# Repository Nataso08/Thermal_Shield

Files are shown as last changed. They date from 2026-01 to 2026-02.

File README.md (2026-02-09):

# 💻 Thermal_Shield 🌡️

Un progetto Arduino per il controllo della temperatura tramite una scheda termica e una ventola. 
<br>

## 🧾 Materiali necessari:
- Arduino UNO
- Scheda termica
- Ventola 12 V
- Ponte H

## 🌡️ Scheda termica:
La scheda termica utilizzata nel nostro sistema è stata realizzata dalla nostra scuola, [Istituto Max Planck (Villorba, TV)](https://maxplanck.edu.it).

### 📐 Struttura:
La scheda termica è strutturata su un PCB e si presenta come riportato nelle seguenti immagini.
<br>

<div style="display:flex; gap:10px;">
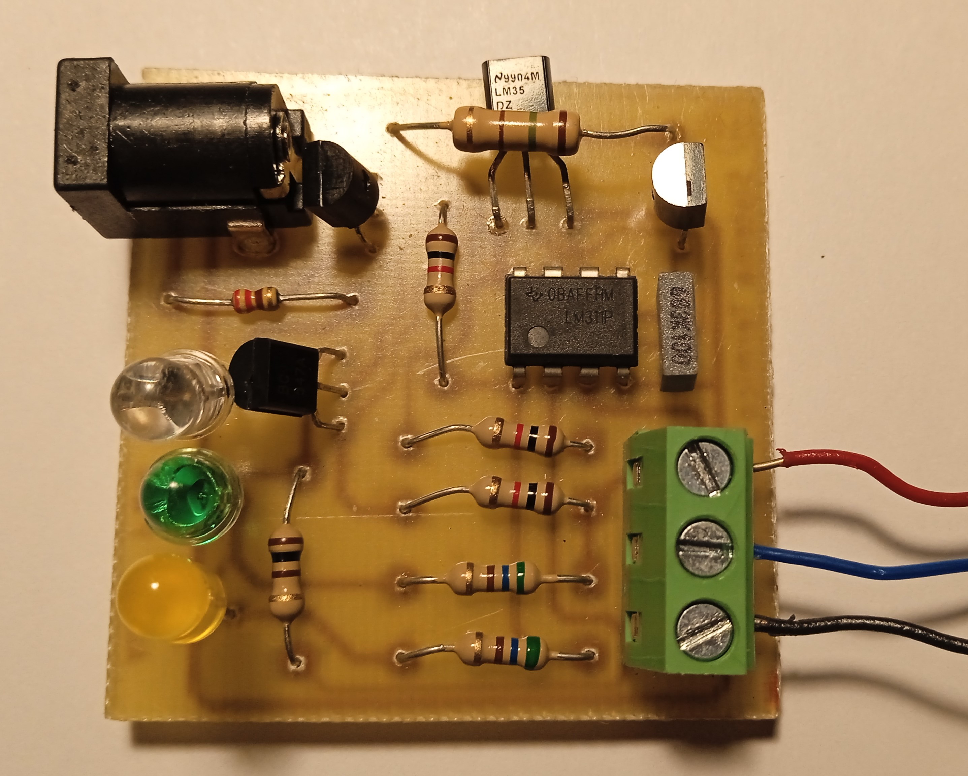
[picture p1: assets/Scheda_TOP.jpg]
Scheda, sopra
  
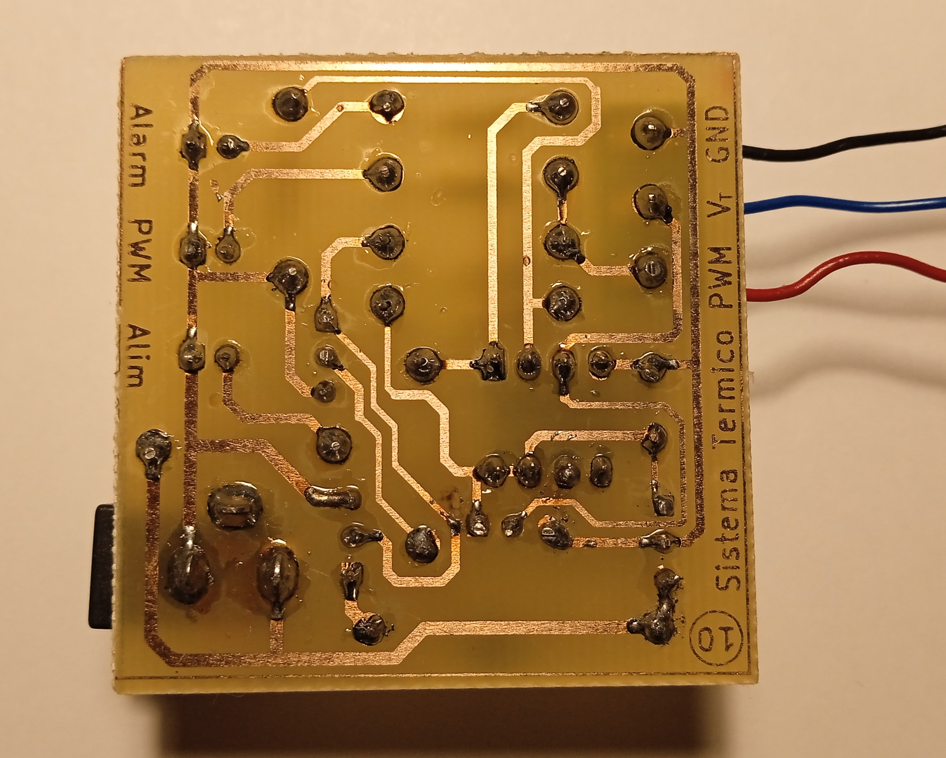
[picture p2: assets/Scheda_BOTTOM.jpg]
Scheda, sotto
  
</div>

### 🖇️ Schema
Di seguito è riportato lo schema elettrico della scheda. <br>
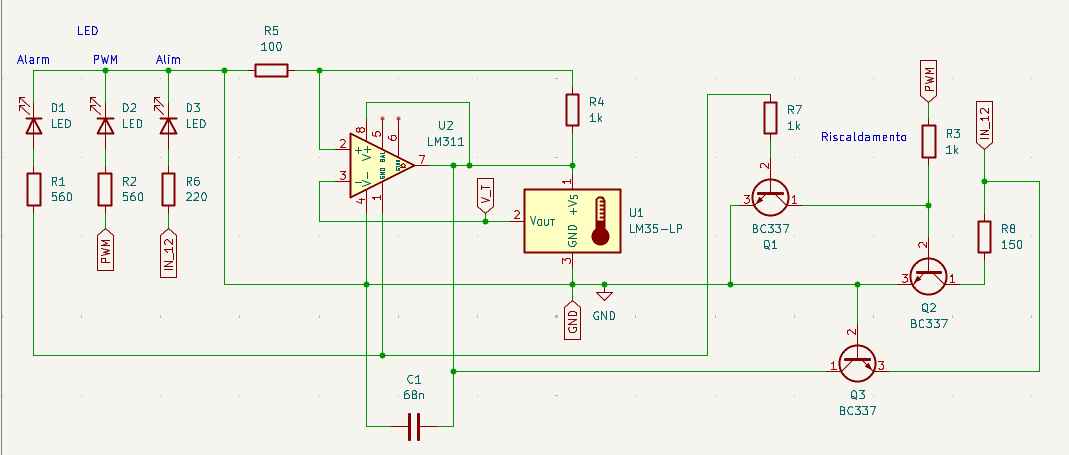
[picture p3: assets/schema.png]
Schema elettrico della scheda


[Progetto Kicad](./Thermal_Shield/Thermal_Shield.kicad_pro)

### 🔌 Collegamenti:

- Alimentare la scheda (jack DC) ad una tensione di 12 V
- Collegare Arduino UNO tramite la morsettiera:
    - GND → GND
    - $V_T$ → Ingresso Analogico di Arduino (A0 - A5)
    - PWM → Uscita PWM di Arduino (pin 3, 5, 6, 9, 10 o 11)

## 💨 Ventola:
Generica ventola 12 V (es. ventola da PC).<br><br>
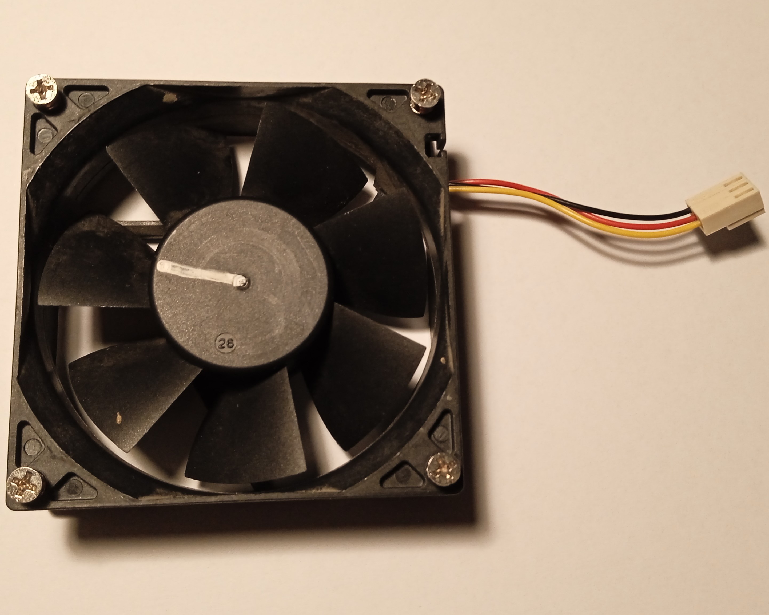
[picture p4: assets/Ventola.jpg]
Ventola 12 V


### 🔌 Collegamenti:
- Power → alimentazione 12 V (tramite [ponte H](#ponte-h))
- GND → GND (comune tra Arduino e alimentazione 12 V)
- RPM → Pin interrupt di Arudino (2, 3)

⚠️ **Non collegare GND all'uscita del ponte H, altrimenti l'encoder non funziona correttamente**. <br>
❗ Nel codice allegato non è presente la misurazione della velocità (RPM) ma è facilmente integrabile.

❗ Collegare 5 V del ponte H a $V_{in}$ di Arduino se si vuole far funzionare il sistema indipendente dall'alimentazione USB. <br>
⚠️ In questo caso, **alimentare il ponte H prima di collegare Arduino con USB** per evitare problemi di alimentazione.
<br><br>

### 🔌 Ponte H:
È possibile usare un qualsiasi ponte H. <br>
Nel mio caso ho utilizzato un L298N, utilizzando esclusivamente il "ramo" B. <br><br>
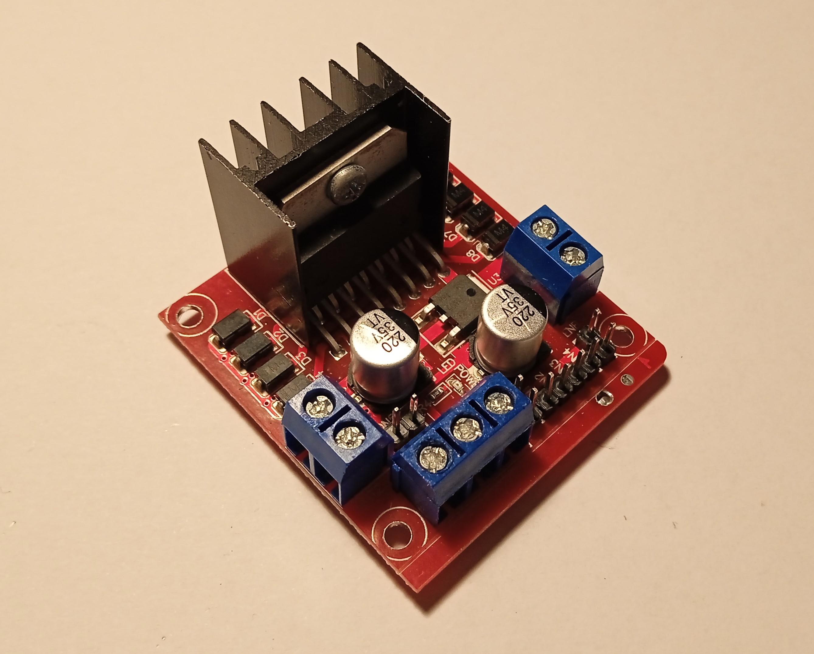
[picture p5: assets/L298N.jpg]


Collegare il pin IN3 (se si utilizza il "ramo" B) ad un'uscita PWM di Arduino (pin 3, 5, 6, 9, 10 o 11). <br>
⚠️ Si può verificare se il l'alimentazione ha polarizzazione corretta cortocircuitando il pin IN3 con i 5 V di Arduino: se la ventola inizia a girare il pin è corretto, altrimenti collegare il pin IN4 (o il complementare della coppia del "ramo" scelto).

#### ❗ Alternative:
Se non si dispone di un ponte H è possibile sostituirlo con un circuito a transistor con dovuto dimensionamento.
<br>

### ⚙️ Filtro segnale PWM:
Poiché il segnale PWM potrebbe non essere propriamente adatto alla tua ventola è consigliabile realizzare un filtro RC come quello di seguito riportato. <br>
...

## 🛠️ Setup:
1) Effettuare i collegamenti sopra descritti
2) Adattare i pin impostati nel [codice allegato](/Thermal_Shield.ino) sulla base delle proprie necessità
3) Impostare i propri valori di T_min e T_max
4) Se necessario, modificare il kp e q (nella funzione FTU) affinché la ventola riesca ad abbassare la temperatura fino a T_min
5) Caricare il [codice allegato](/Thermal_Shield.ino) e aggiornato (vedi punto 2) su Arduino tramite Arduino IDE

## 💻 Utilizzo:

### 🟢 Azionamento:
Si può azionare il sistema tramite:
1) Pressione del pulsante Start
2) Scrittura '1' su Seriale

A seguito di una delle 2 azioni il sistema inizierà il suo ciclo di riscaldamento/raffreddamento.

### 🔴 Spegnimento:
Si può fermare il sistema tramite:
1) Pressione del pulsante Stop
2) Scrittura '0' su Seriale

A seguito di una delle 2 azioni il sistema si fermerà togliendo alimentazione a resistenza riscaldante e ventola (non svolge però la funzione di freno alla ventola, che continuerà a ruotare per inerzia).

### 📊 Misurazione / rappresentazione grafica:
È possibile osservare il variare della temperatura tramite la lettura della comunicazione seriale. In particolare:
- **Monitor Seriale**: Permette una facile lettura dei dati "grezzi" 📄
- **Plotter Seriale**: Permette una facile visualizzazione grafica del variare dei valori 📉

<br>
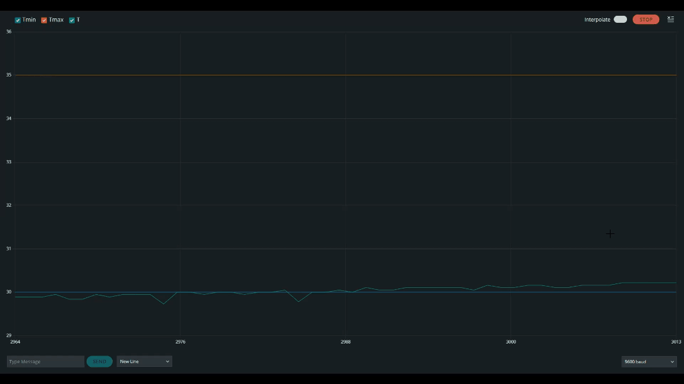
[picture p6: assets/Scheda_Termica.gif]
Grafico Temperatura


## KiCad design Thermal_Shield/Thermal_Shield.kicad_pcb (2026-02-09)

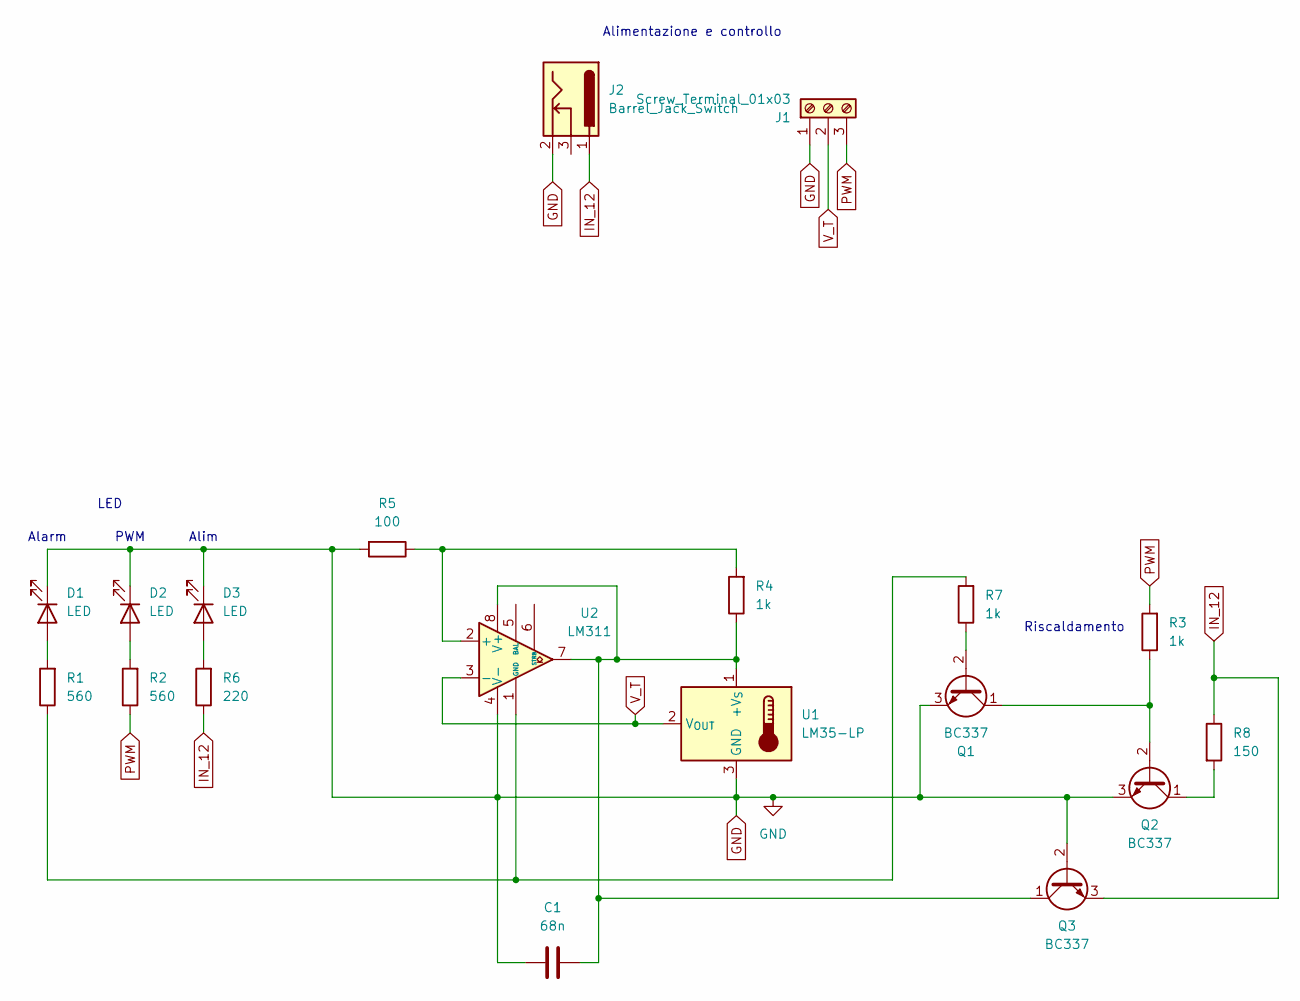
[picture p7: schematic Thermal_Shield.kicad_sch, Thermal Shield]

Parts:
C1: 68n; C_Rect_L7.2mm_W2.5mm_P5.00mm_FKS2_FKP2_MKS2_MKP2
D1, D2, D3: LED; LED_D4.0mm
J1: Screw_Terminal_01x03; TerminalBlock_MaiXu_MX126-5.0-03P_1x03_P5.00mm
J2: Barrel_Jack_Switch; BarrelJack_Horizontal
Q1, Q2, Q3: BC337; TO-92_Inline_Wide
R1, R2: 560; R_Axial_DIN0309_L9.0mm_D3.2mm_P12.70mm_Horizontal
R3, R4, R7: 1k; R_Axial_DIN0309_L9.0mm_D3.2mm_P12.70mm_Horizontal
R5: 100; R_Axial_DIN0309_L9.0mm_D3.2mm_P12.70mm_Horizontal
R6: 220; R_Axial_DIN0309_L9.0mm_D3.2mm_P12.70mm_Horizontal
R8: 150; R_Axial_DIN0309_L9.0mm_D3.2mm_P20.32mm_Horizontal
U1: LM35-LP; TO-92_Inline_Wide
U2: LM311; DIP-8_W7.62mm

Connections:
GND: C1.2, D1.1 (K), D2.1 (K), D3.1 (K), J1.1, J2.2, Q1.3 (E), Q2.3 (E), Q3.2 (B), R5.2, U1.3 (GND), U2.4 (V-)
IN_12: J2.1, Q3.3 (E), R6.1, R8.1
unnamed: D1.2 (A), R1.2
unnamed: D2.2 (A), R2.2
unnamed: D3.2 (A), R6.2
unnamed: Q1.2 (B), R7.1
unnamed: Q1.1 (C), Q2.2 (B), R3.1
unnamed: Q2.1 (C), R8.2
unnamed: C1.1, Q3.1 (C), R4.1, U1.1 (+V_{S}), U2.7, U2.8 (V+)
unnamed: R4.2, R5.1, U2.2 (+)
unnamed: R1.1, R7.2, U2.1 (GND)
PWM: J1.3, R2.1, R3.2
V_T: J1.2, U1.2 (V_{OUT}), U2.3 (-)

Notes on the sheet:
LED
Riscaldamento
PWM
Alim
Alarm
Alimentazione e controllo

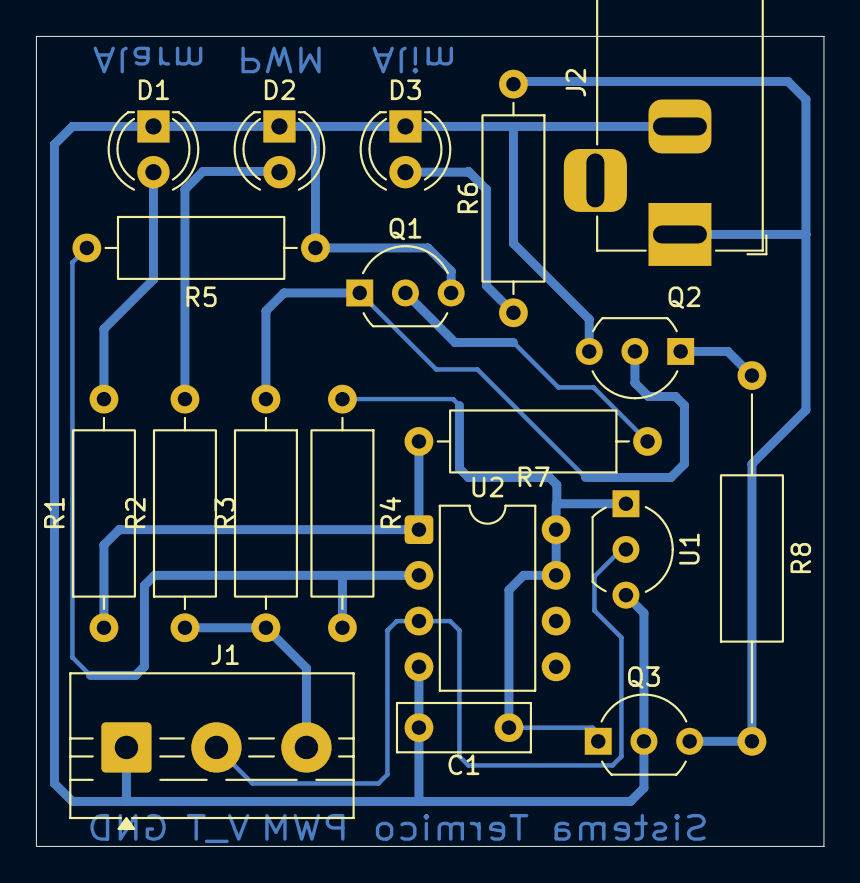
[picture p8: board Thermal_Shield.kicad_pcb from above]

Board: 2 copper layers, 43.8 x 45.0 mm, 19 parts (0 on the bottom side), 13 nets.

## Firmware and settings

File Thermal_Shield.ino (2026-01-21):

#include "mylibrary.h"

/*
PWM Arduino UNO
Pin   | Frequenza   | Timer   | Modalità
3       488 Hz        2         Fast PWM / Phase-correct
5       976 Hz        0         Fast PWM
6       976 Hz        0         Fast PWM
9       488 Hz        1         Fast PWM
10      488 Hz        1         Fast PWM  
11      488 Hz        2         Fast PWM / Phase-correct

Prescaler = 64 per tutti, di default

Definizioni di modalità:
- Fast PWM:
  0 -> TOP (salita) -> 0 (azzero) -> TOP ...
  f_PWM = (16 * 10^6) / (64 * 256) = 976 Hz
- Phase-correct
  0 -> TOP (salita) -> 0 (discesa) -> TOP ...
  f_PWM = (16 * 10^6) / (64 * 2 * 256) = 488 Hz
*/

float T, T_last, T_med, T_max = 35, T_min = 30;      // range di valori nel quale deve essere mantenuta la temperatura

short T_value;      // valore temperatura analogica (0-1023)
short PWM_resistenza, PWM_ventola;    // valore da applicare a pin PWM

// pulsanti START e STOP basati sulla libreria dello scorso anno (debounce e fronti con OOP)
Pulsante Start (4, INPUT_PULLUP, 'n');
Pulsante Stop (5, INPUT_PULLUP, 'n');

#define pinResistenza 10
#define pinVentola 11
#define pinTemp A0

// variabili di stato e definizione stati
char stato, stato_old;
#define ATTESA 0
#define SCALDA 1
#define RAFFREDDA 2

// dichiarazioni funzioni per macchina a stati (Moore)
void FTS ();
void FTU ();
void leggiIngressi ();
void scriviUscite ();

char lettura = '\n';

void setup() {
  // inizializzazione dei pulsanti
  Start.init();
  Stop.init();

  DDRB |= ((1<<PB2) | (1<<PB3));       // setup pin 10 e 11 in OUTPUT tramite registri
  DDRC &= ~(1<<PC0);                   // setup pin A0 in INPUT tramite registri

  // reset variabili di stato
  stato = ATTESA;
  stato_old = 3;

  // analogReference(DEFAULT);           // riferimento default 5 V
  analogReference(INTERNAL);          // riferimento interno 1.1 V
  // analogReference(EXTERNAL);       // riferimento esterno AREF (es. 3.3 V)

  Serial.begin(9600);     // inizializzazione seriale
}

void loop() {
  leggiIngressi ();
  FTS ();
  FTU ();
  scriviUscite ();
}


void FTS () {
  // aggiornamento stato_old
  stato_old = stato;

  // stato = ATTESA se STOP
  if (Stop.f_UP || lettura == '0')
    stato = ATTESA;

  // FTS con controllo temperature (mantenimento tra T_min e T_max)
  switch (stato) {
    case SCALDA:
      if (T_med >= T_max) 
        stato = RAFFREDDA;
      break;
    case RAFFREDDA:
      if (T_med <= T_min) 
        stato = SCALDA;
      break;
    case ATTESA:
    default:
      if (Start.f_UP || lettura == '1')
        stato = SCALDA;
      break;
  }
}

void FTU () {
  // assegnazione valori PWM in base a stato attuale
  switch (stato) {
    case SCALDA:
      PWM_resistenza = 200;
      PWM_ventola = 0;
      break;
    case RAFFREDDA:
      PWM_resistenza = 0;
      // PWM_ventola proporzionale alla differenza di temperatura (più veloce se errore grande)
      double kp = 230, q = 10;
      PWM_ventola = (byte) kp /(T_max - T_min) *(T_med - T_min) + q;
      break;
    case ATTESA:
    default:
      PWM_resistenza = 0;
      PWM_ventola = 0;
      break;
  }
}

void leggiDigital () {
  // lettura pin digitali (START e STOP)
  Start.fronte();
  Stop.fronte();
}
void leggiAnalog () {
  // lettura pin analogici (A0 -> temperatura) ogni 100 ms
  static unsigned long analogTime = 0;    // variabile statica (solo nella funzione, ma mantiene valore)

  if (millis() - analogTime >= 50) {
    analogTime = millis();                

    T_last = T;

    T_value = analogRead (pinTemp);            // lettura analogica di A0
    // calcolo Temperatura con proporzione  
    // lettura : 1023 = T : T_max

    // T = (float) T_value * 500.0 / 1023.0;     // proporzione con REF = 5 V (DEFAULT)
    T = (float) T_value * 110.0 / 1023.0;     // proporzione con REF = 1.1 V (INTERNAL)
    // T = (float) T_value * 330.0 / 1023.0;     // proporzione con es. REF = 3.3 V (EXTERNAL)

    T_med = (T + T_last) /2.0;                // temperatura media ultimi 2 valori -> aiuta a filtraggio software
  } 
}
void leggiSerial () {
  // lettura seriale (char) -> solo "fronte" (se c'è qualcosa salvo quel valore, altrimenti '\n')
  if (Serial.available()) {
    lettura = Serial.read();
  } else lettura = '\n';
}
void leggiIngressi() {
  leggiDigital ();
  leggiAnalog ();
  leggiSerial ();
}


void scriviDigital () {
  // assegnazione valori pin digitali
}
void scriviAnalog () {
  // assegnazione valori pin analogici
  analogWrite(pinResistenza, PWM_resistenza);   // scrittura analogica PWM su pin 10 (resistenza)
  analogWrite(pinVentola, PWM_ventola);
}
void scriviSerial () {
  // scrittura seriale ogni 100 ms (in formato Serial Plotter)
  static unsigned long serialTime = 0;

  if (millis() - serialTime >= 100) {
    serialTime = millis();

    Serial.print ("Tmin:");
    Serial.print (T_min);

    Serial.print (" Tmax:");
    Serial.print (T_max);

    Serial.print (" T:");
    Serial.print (T_med);

    Serial.print ('\n');
  }
}
void scriviUscite () {
  scriviDigital ();
  scriviAnalog ();
  scriviSerial ();
}

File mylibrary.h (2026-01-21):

#ifndef myLibrary
#define myLibrary .h

// dichiaro le costanti del codice (wait di default)
#define DT_WAIT_DEBOUNCE 20
#define DT_M 10000
#define DT_LUCE 1000

// dichiaro classe madre (idealmente astratta, quindi utilizzabile solo da altre classi come stampo; nella pratica accessibile anche dall'esterno (solo public))
class Pin {
  protected: // accessibili solo da sottoclassi
    char set_up;
    unsigned short pin;

    Pin(unsigned short pin, char set_up) : pin(pin), set_up(set_up) {}  // metodo costruttore

  public:
    bool s;

    void init () {
      pinMode (pin, set_up);
    }
};

// dichiaro classe Pulsante come sottoclasse di Pin (assume come propri tutti i parametri e metodi di Pin)
class Pulsante : public Pin {
  private:    // variabili private della classe Pulsante (definizioni + variabili delle funzioni + costanti)
    #define ATTESA 0
    #define CONTROLLO 1
    #define PREMUTO 2
    
    bool lettura;
    char stato_digitalRead_debounced = ATTESA;

    bool letturaFronte;
    bool letturaFronte_old;

    bool POff;
    bool POn;

    int dt_wait_debounce;

    char logic;

    unsigned long tempo;

  public:
    bool f_UP, f_DOWN;

    Pulsante (unsigned short pin, char set_up, char logic = 'p', int dt_wait_debounce = DT_WAIT_DEBOUNCE) : Pin(pin, set_up), logic(logic), dt_wait_debounce(dt_wait_debounce) { 
      // metodo costruttore che richiama metodo costruttore di Pin

      if (logic == 'p') { // assegno valori di POn e POff
        POn = 1;
        POff = 0;
      } else {
        POn = 0;
        POff = 1;
      }
    }

    void digitalRead_debounced () { // digitalRead con debounce
    
      lettura = digitalRead(pin);
    
      switch (stato_digitalRead_debounced) {
        case ATTESA:
          if (lettura == POn){
            stato_digitalRead_debounced = CONTROLLO;
            tempo = millis();
          }
          break;
    
        case CONTROLLO:
          if ((millis() - tempo) > dt_wait_debounce) {
            if (lettura == POn)
              stato_digitalRead_debounced = PREMUTO;
            if (lettura == POff)
              stato_digitalRead_debounced = ATTESA;
          }
          break;
    
        case PREMUTO:
          if (lettura == POff)
            stato_digitalRead_debounced = ATTESA;
          break;
      }
    
      switch (stato_digitalRead_debounced) {
        case ATTESA:
        case CONTROLLO:
          s = false;
          break;
    
        case PREMUTO:
          s = true;
          break;
      }
    }


    void fronte () {    // lettura fronti (UP e DOWN assieme)
      letturaFronte_old = letturaFronte;
      digitalRead_debounced();
      letturaFronte = s;
      
      if (letturaFronte == 1 && letturaFronte_old == 0)
        f_UP = true;
      else
        f_UP = false;
      
      if (letturaFronte == 0 && letturaFronte_old == 1)
        f_DOWN = true;
      else
        f_DOWN = false;
    }
  
};

// dichiaro classe Motore come sottoclasse di Pin (assume come propri tutti i parametri e metodi di Pin)
class Motore : public Pin {
  private:
    unsigned long dt_M;
    unsigned long t;
    bool s_old;

  public:
    bool f_UP, f_DOWN;

    Motore (unsigned short pin, unsigned long dt_M = DT_M) : Pin(pin, OUTPUT), dt_M(dt_M) {
      // metodo costruttore che richiama metodo costruttore di Pin
    }

    void ON () {  // attivo
      s_old = s;
      s = 1;
      f_UP = ((s_old == 0 && s == 1) ? 1 : 0);
    }

    void OFF () { // spento
      s_old = s;
      s = 0;
      f_DOWN = ((s_old == 1 && s == 0) ? 1 : 0);
    }

    void scrivi () {  // scrittura (per scriviUscite)
      digitalWrite(pin, s);
    }

    void updateTime () {  // aggiornamento variabile tempo (privata)
      t = millis();
    }

    bool doneTime () {    // verifico se è passato il tempo
      return millis() - t >= dt_M;
    }
};


// dichiaro classe Led come sottoclasse di Pin (assume come propri tutti i parametri e metodi di Pin)
class Led : public Pin {
  private:
    bool enable;

    unsigned int dt_luce;
    unsigned long t_luce;
    
    void updateTime () {
      t_luce = millis();
    }


  public:
    Led (unsigned short pin, unsigned int dt_luce = DT_LUCE) : Pin(pin, OUTPUT), dt_luce(dt_luce) {
      // metodo costruttore che richiama metodo costruttore di Pin
    }


    void ON () {  // led on
      s = 1;
      enable = 1;
    }

    void OFF () { // led off
      s = 0;
      enable = 1;
    }

    void ENABLE (bool enable = 1) { // serve per segnalazione (caso favorevole o meno)
      this->enable = enable;
    }

    void scrivi () {    // scrittura (per scriviUscite)
      digitalWrite(pin, s && enable);
    }

    void segnalazione () {  // segnalazione (lampeggiante)
      if (millis() - t_luce >= dt_luce) {
        s = !s;
        updateTime();
      }
    }
};


#endif

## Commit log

2026-01-21 Codice Arduino della scheda termica (file .ino + libreria .h + datasheet LM35.pdf
2026-02-08 PCB ready to connections
    [Thermal_Shield.kicad_pcb, Thermal_Shield.kicad_sch]
